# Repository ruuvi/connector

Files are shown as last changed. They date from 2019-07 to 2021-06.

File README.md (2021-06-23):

# Ruuvi Connector system

Ruuvi Connector is a standardised expansion connector and cable system that takes sensor prototyping to the next level. Compatible connectors will be found on many upcoming Ruuvi products.

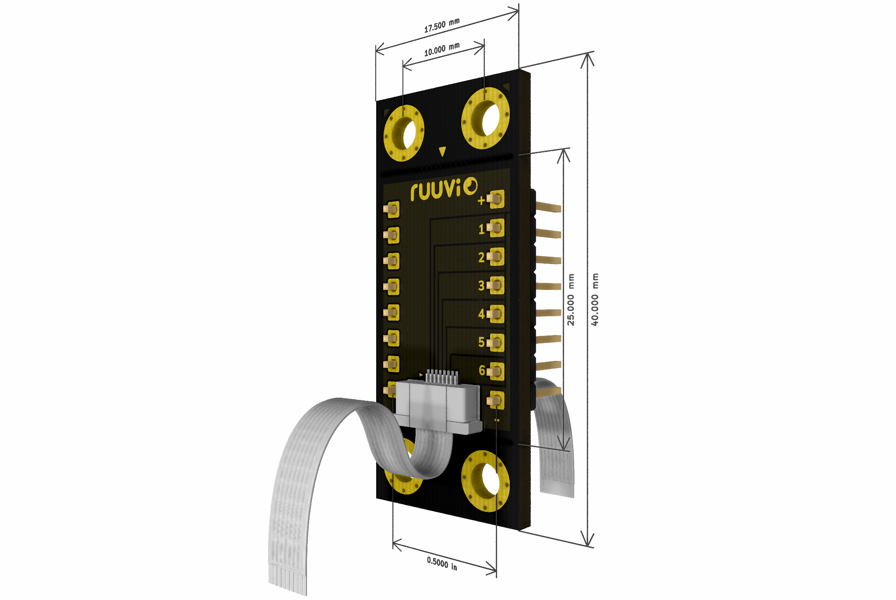
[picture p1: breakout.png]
Ruuvi Connector Breakout Board


There are many ways on how to use the Ruuvi Connector system:

1) Connect compatible external boards and sensors to your Ruuvi products
2) Design your own Ruuvi Connector expansion boards
3) Feed your battery powered Ruuvi products from external power sources
4) Add a Ruuvi Connector compatible connector on your own product and make it compatible with all the external Ruuvi / Grove / Qwiic / STEMMA / Gravity sensors
5) Innovate and create something totally new

Ruuvi Connector is compatible with 4-pin (2 signals + VDD + GND) prototyping systems such as [Seeed Studio Grove](http://wiki.seeedstudio.com/Grove_System/), [Sparkfun Qwiic](https://www.sparkfun.com/qwiic), [Adafruit STEMMA](https://learn.adafruit.com/introducing-adafruit-stemma-qt/), [DFRobot Gravity](https://www.dfrobot.com/gravity) and more.

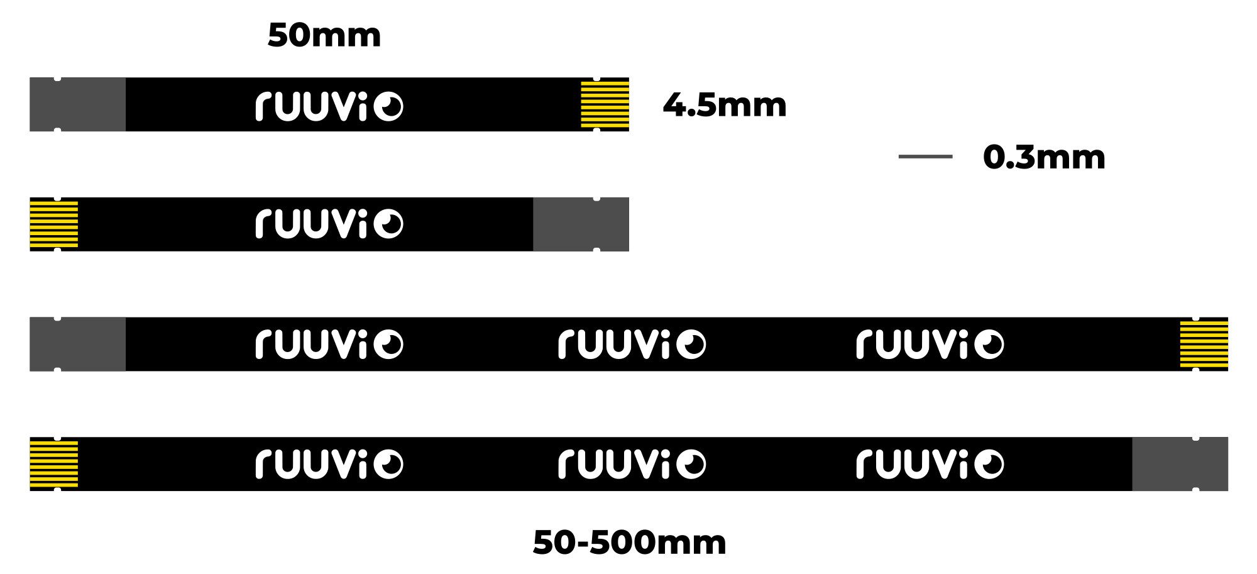
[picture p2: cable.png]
Ruuvi Connector cables


## Ruuvi Connector pin-out

Ruuvi Connector cables have 8 pins (6 signals + VDD + GND). This allows using not just simple I2C sensors but also more powerful SPI sensors equipped with interrupt signals.

Note that on RuuviTags that have Ruuvi Connectors available, pins 2 and 3 are shared with internal I2C sensors. Also pin 7 is connected to TMP117 temperature sensor's interrupt signal (if a TMP117 is populated) but because the interrupt pin is an open-drain output and because it's not active in the Ruuvi firmware by default, it doesn't reserve the pin and it can be safely used for other purposes as long as TMP117 isn't configured to pull it down.

1) VDD (1.8V - 3.6V, default = 3.3V)
2) I2C_SCL / UART_RXD / ADC / GPIO
3) I2C_SDA / UART_TXD / ADC / GPIO
4) SPI_MISO / ADC / GPIO
5) SPI_MOSI / ADC / GPIO
6) SPI_SCK / ADC / GPIO
7) SPI_CS / ADC / GPIO
8) GND

Default FPC connector is [AFC07-S08ECA-00](https://lcsc.com/product-detail/Others_JUSHUO-AFC07-S08ECA-00_C262581.html).
## Dimensions of expansion boards 

1) 17.5 x 40 mm (17.5 x 25 mm without mounting holes). Used on the breakout board. 
2) 11 x 25 mm. Used on the external temperature sensor board.
3) TBD

## License

All the design files in this repository are licensed using Attribution-ShareAlike 4.0 International (CC BY-SA 4.0). Copyright: Ruuvi Innovations Ltd (Oy). Neither the name of the Ruuvi nor the names of its contributors may be used to endorse or promote products derived from this project without a specific prior written permission. While unofficial products should not have "Ruuvi" in their name, it's okay to describe your product in relation to the Ruuvi projects. More info: license@ruuvi.com.

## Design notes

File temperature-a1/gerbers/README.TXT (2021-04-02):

Ruuvi Temperature A1
====================

Board Size: 		11x25mm
Material: 		FR4
Layers: 			2
Silkscreen: 		NO
Solder masks: 		Matte Black, top & bottom
Plating: 		Immersion Gold

Minimum clearance: 	0.15mm
Minimum trace width: 	0.15mm
Minimum hole diameter:	0.30mm

Stack-up
========

TOP = 1 oz (35um) copper
0.7mm FR4 prepreg (+-0.1mm)
BOT = 1 oz (35um) copper

Total thickness: 0.8mm (+-0.1mm)

Paneling
========

10 x 5 with 10mm borders. Panel total size = 130 x 145 mm.

Board separation method: v-cuts.

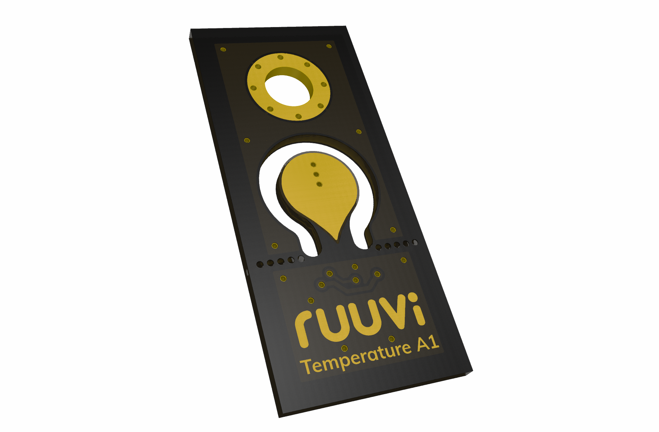
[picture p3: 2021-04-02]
temperature-a1/gerbers/temperature-a1.png

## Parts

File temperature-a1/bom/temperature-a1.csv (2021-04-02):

U1 | TMP117AIDRVR
C1 | 1uF 10V 20% X8R 0603
J1 | AFC07-S08ECA-00

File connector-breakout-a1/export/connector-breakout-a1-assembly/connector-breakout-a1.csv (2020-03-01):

Designator | Quantity | Designation | Part Number
J4,J1 | 2 | Ruuvi Connector Horizontal | AFC07-S08ECA-00

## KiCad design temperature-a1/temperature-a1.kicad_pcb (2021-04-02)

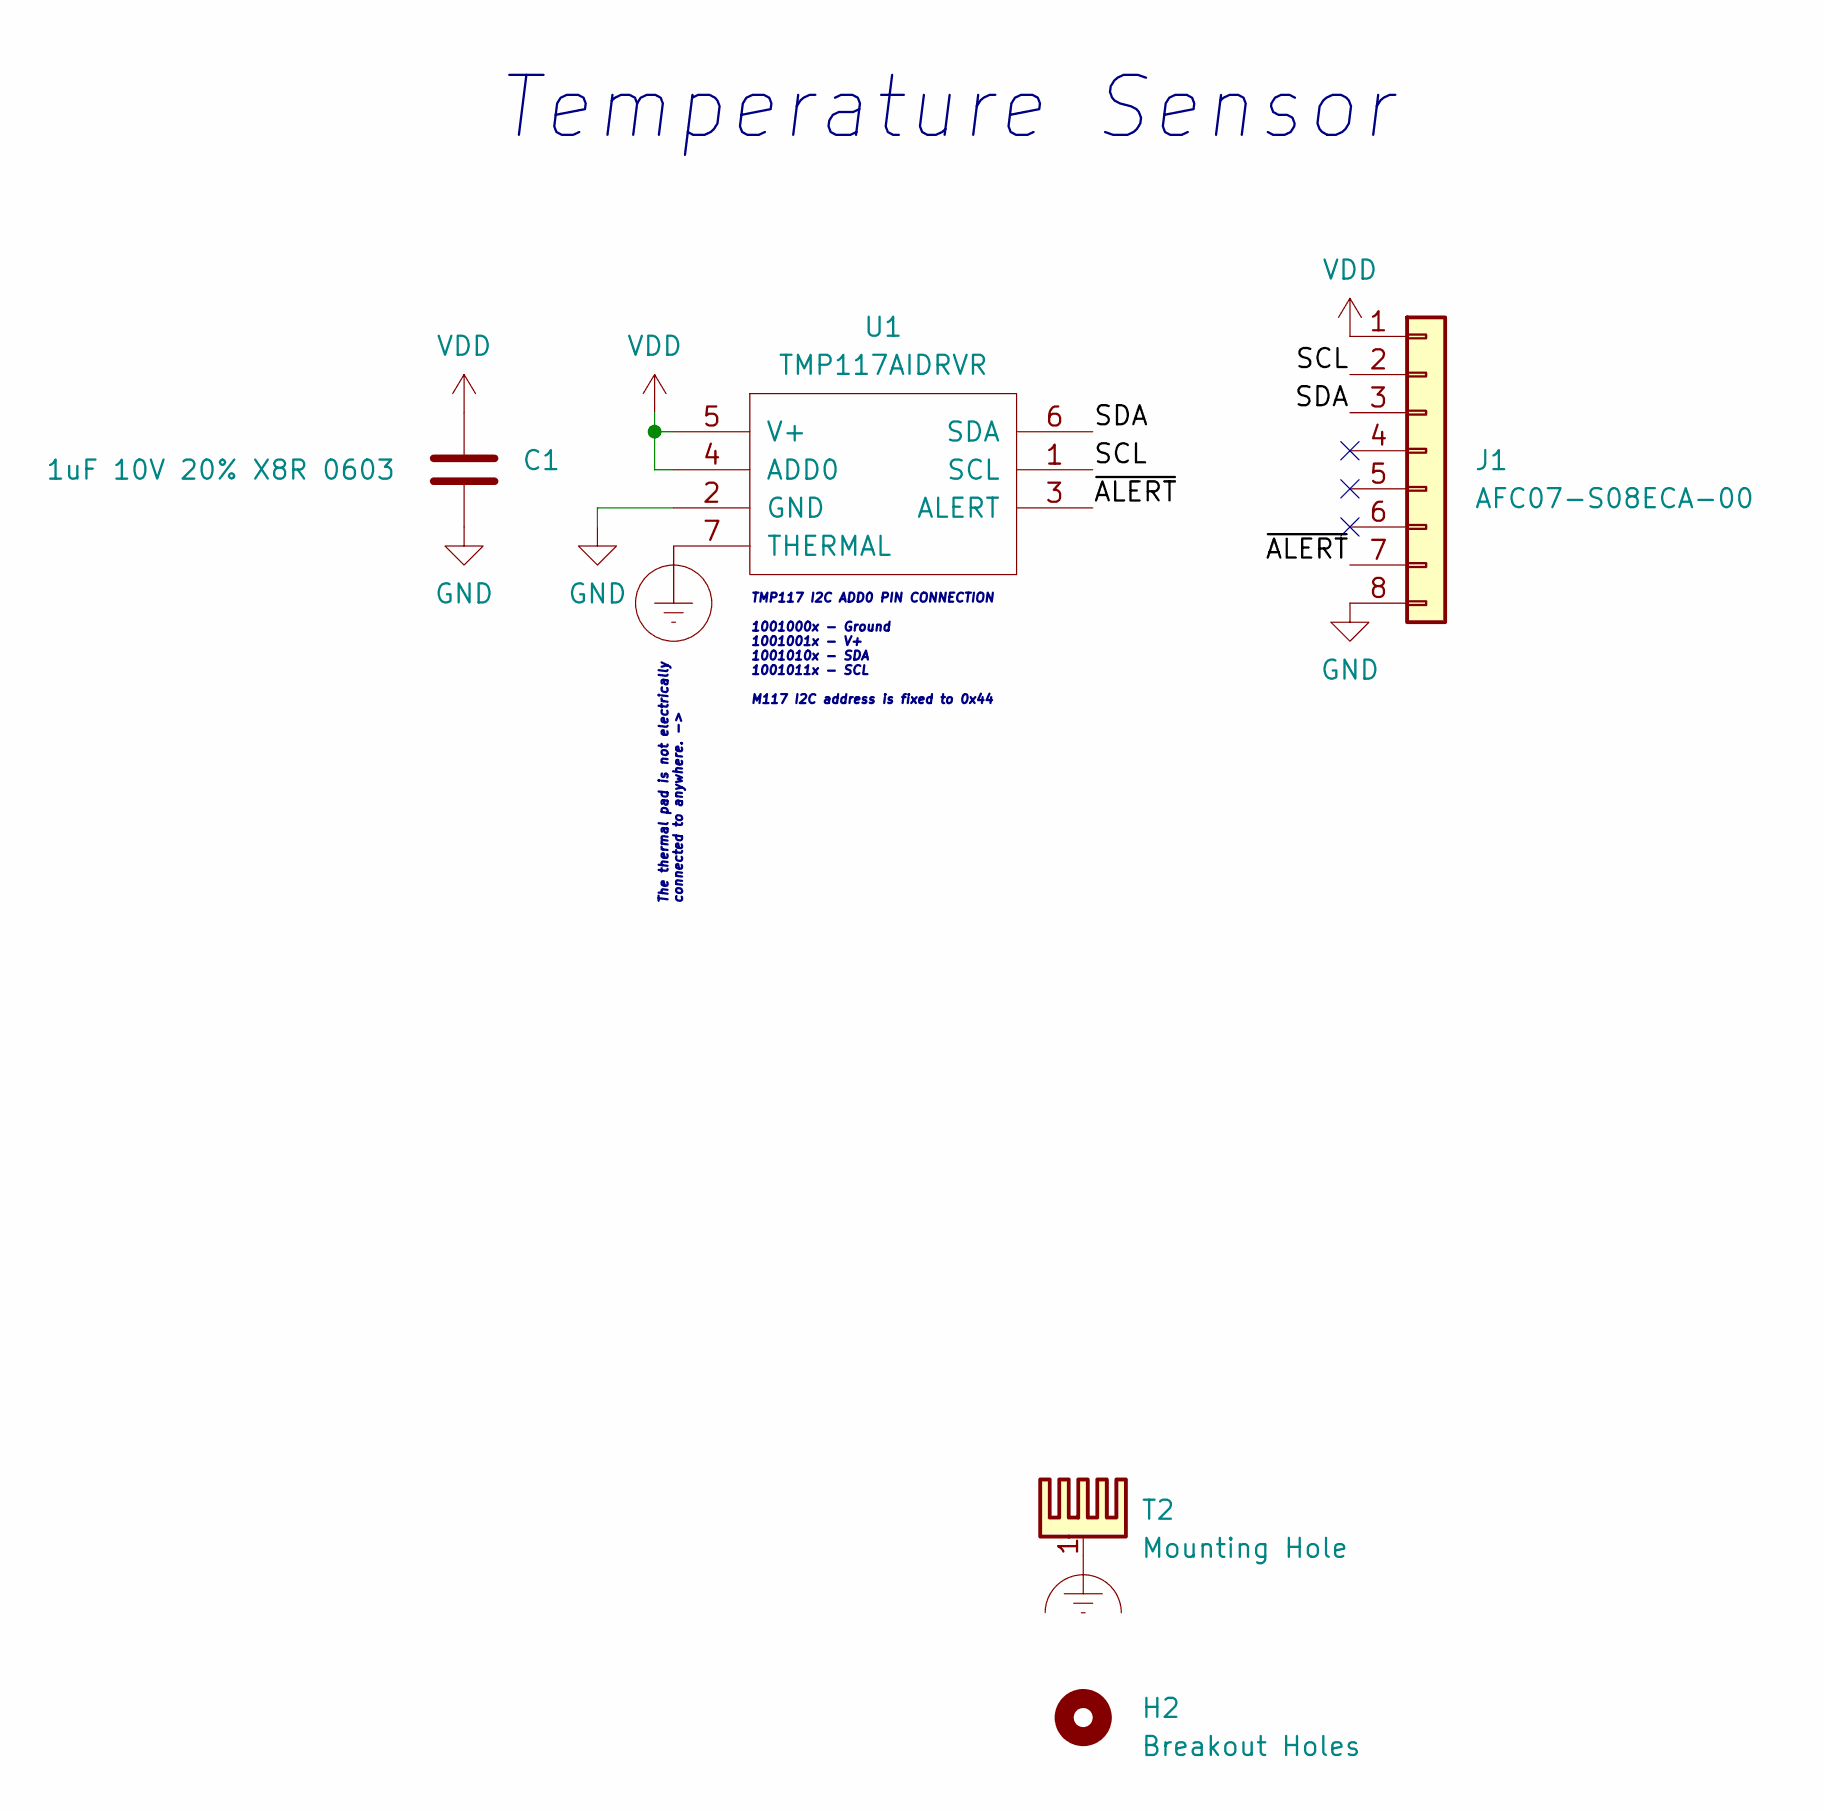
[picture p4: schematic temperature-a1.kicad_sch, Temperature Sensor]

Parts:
C1: 1uF 10V 20% X8R 0603; 0603_CAP
H2: Breakout Holes; BreakoutHoles
J1: AFC07-S08ECA-00; RUUVI_CONNECTOR_FFC
T2: Mounting Hole; MountingHole_3.2mm_M3_Pad_Via
U1: TMP117AIDRVR; WSON6

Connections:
/SCL: J1.2, U1.1 (SCL)
/SDA: J1.3, U1.6 (SDA)
/~ALERT: J1.7, U1.3 (ALERT)
Earth_Clean: T2.1
Earth_Protective: U1.7 (THERMAL)
GND: C1.2, J1.8, U1.2 (GND)
VDD: C1.1, J1.1, U1.4 (ADD0), U1.5 (V+)

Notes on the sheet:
The thermal pad is not electrically connected to anywhere. ->
TMP117 I2C ADD0 PIN CONNECTION 1001000x - Ground 1001001x - V+ 1001010x - SDA 1001011x - SCL M117 I2C address is fixed to 0x44
Temperature Sensor

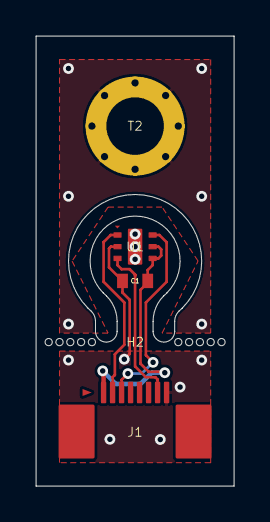
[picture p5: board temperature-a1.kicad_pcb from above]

Board: 2 copper layers, 11.0 x 25.0 mm, 5 parts (0 on the bottom side), 5 nets.

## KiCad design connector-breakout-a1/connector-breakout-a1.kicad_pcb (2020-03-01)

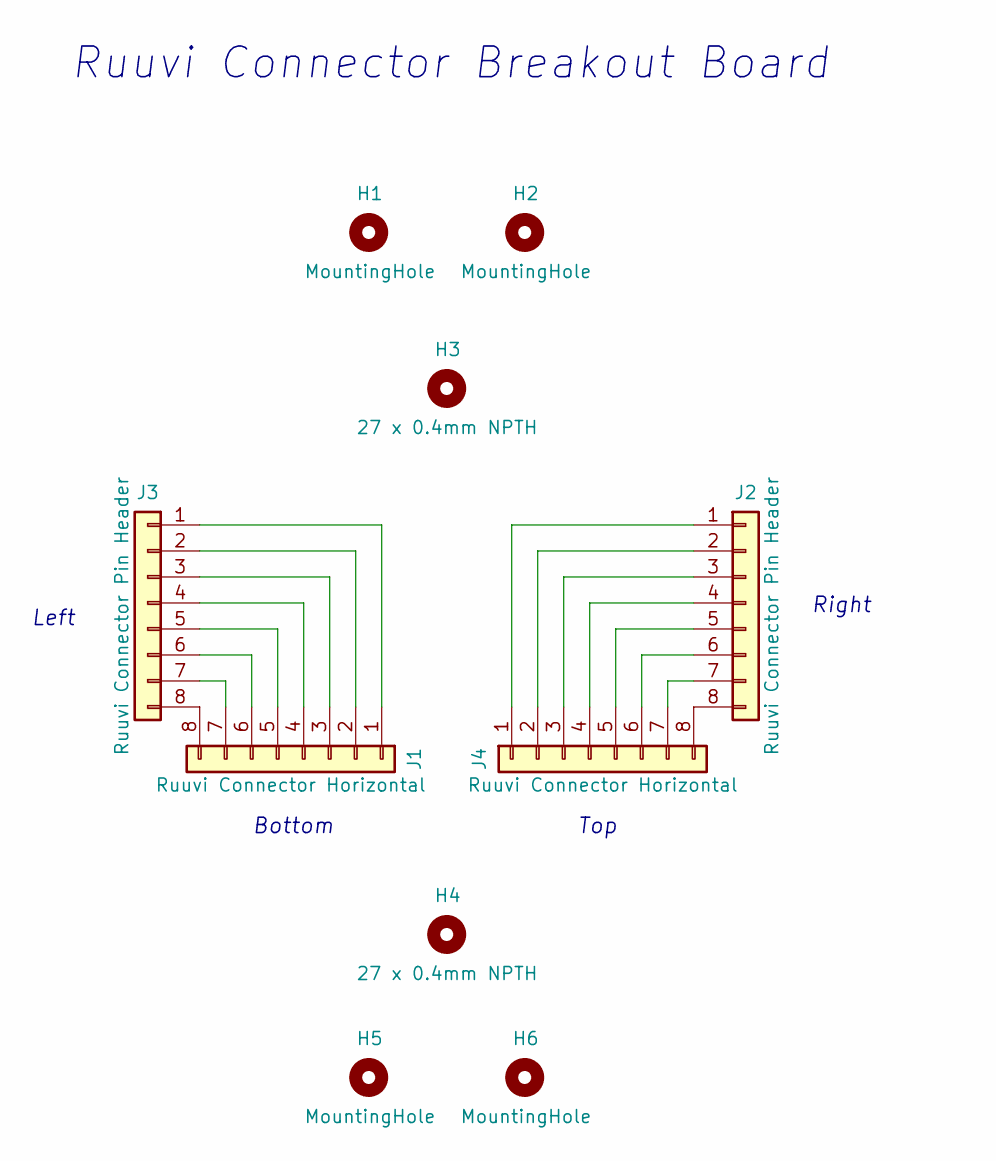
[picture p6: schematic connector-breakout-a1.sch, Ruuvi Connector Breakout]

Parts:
H1, H2, H5, H6: MountingHole; MountingHole_3.2mm_M3_Pad_Via
H3, H4: 27 x 0.4mm NPTH; BreakoutHoles
J1, J4: Ruuvi Connector Horizontal; RUUVI_CONNECTOR_FFC
J2, J3: Ruuvi Connector Pin Header; RUUVI_CONNECTOR_8PIN_HEADER

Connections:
unnamed: J1.1, J3.1
unnamed: J1.2, J3.2
unnamed: J1.3, J3.3
unnamed: J1.4, J3.4
unnamed: J1.5, J3.5
unnamed: J1.6, J3.6
unnamed: J1.7, J3.7
unnamed: J1.8, J3.8
unnamed: J2.1, J4.1
unnamed: J2.2, J4.2
unnamed: J2.3, J4.3
unnamed: J2.4, J4.4
unnamed: J2.5, J4.5
unnamed: J2.6, J4.6
unnamed: J2.7, J4.7
unnamed: J2.8, J4.8

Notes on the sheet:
Ruuvi Connector Breakout Board
Bottom
Top
Left
Right

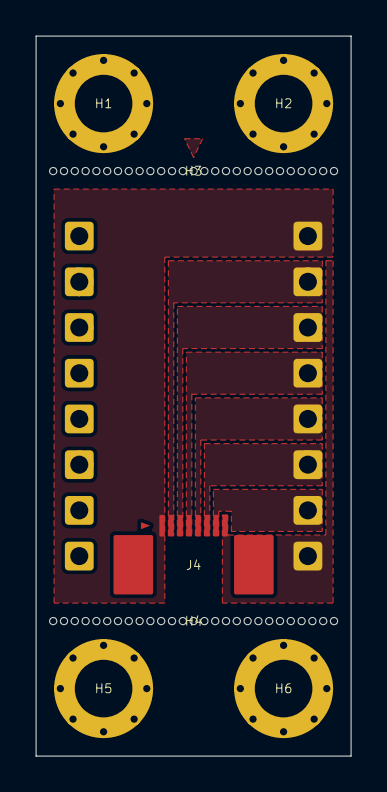
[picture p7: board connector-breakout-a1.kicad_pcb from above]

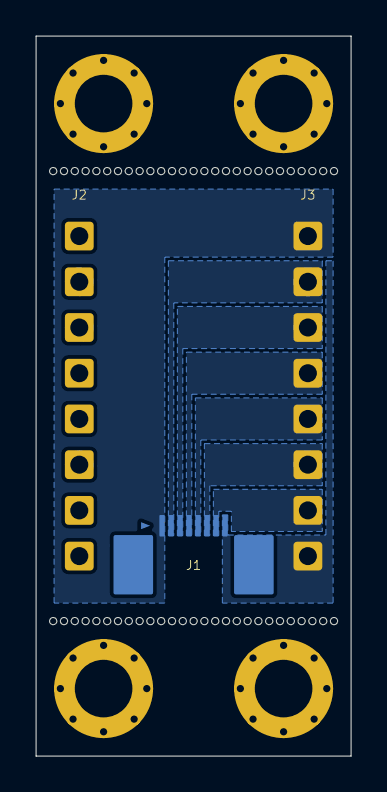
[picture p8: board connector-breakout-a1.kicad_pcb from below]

Board: 2 copper layers, 17.5 x 40.0 mm, 10 parts (3 on the bottom side), 16 nets.

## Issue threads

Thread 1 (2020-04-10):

License file is missing

ojousima, 2020-04-10:
The schematic has CC-SA 4.0 license, but the license can't be found without opening the project files in KiCAD

laurijamsa, 2020-04-10:
License info added on bottom of the README.md.

Closed 2020-04-10.

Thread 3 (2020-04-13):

Dimensions: Specify distances from board edges

ojousima, 2020-04-13:
Add a dimensions from corner of a board to the center of mounting hole and to pin 1 of pin header to be explicit about placement

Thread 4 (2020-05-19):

Parts: Specify the FPC connector

ojousima, 2020-05-19:
It's possible to find the exact FPC Connector of breakout AFC07-S08ECA-00 in the production file export, but that takes unnecessary amount of work.

Suggested fix: add the connector to README

Closed 2020-07-31.

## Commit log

2020-02-15 Add Breakout A1
    [connector-breakout-a1-B_Cu.gbl, connector-breakout-a1-B_Mask.gbs, connector-breakout-a1-B_Paste.gbp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]
2020-03-01 Create BOM and component positioning file
    [connector-breakout-a1.csv, connector-breakout-a1.kicad_pcb]
2020-05-19 Add FPC Connector model of breakout board.
    Fixes #4.
2021-03-28 New project template using the latest Kicad nightly build 20210228
    [temperature-a1.kicad_pcb, temperature-a1.kicad_sch]
2021-03-28 Add a lib, initialise, no content yet
    [temperature-a1.kicad_sch]
2021-03-28 Add TMP117, connector, pull-ups and a bypass cap
    [temperature-a1.kicad_sch]
2021-03-29 First revision, drc pass
    [temperature-a1.kicad_pcb, temperature-a1.kicad_sch]
2021-04-02 Add BOM
    [temperature-a1.csv]
2021-04-02 Export gerbers
    [temperature-a1-B_Cu.gbl, temperature-a1-B_Mask.gbs, temperature-a1-Edge_Cuts.gm1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]
2021-04-02 Several minor updates and layout polishing
    [temperature-a1.kicad_pcb, temperature-a1.kicad_sch]
2021-06-23 Major pinout update to clarify usage with RuuviTags that have shared I2C
